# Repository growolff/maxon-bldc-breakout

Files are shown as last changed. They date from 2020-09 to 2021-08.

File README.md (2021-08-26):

# maxon_bldc_pcb

[][cc-by]

PCB para controlador de motor maxon BLDC 5w

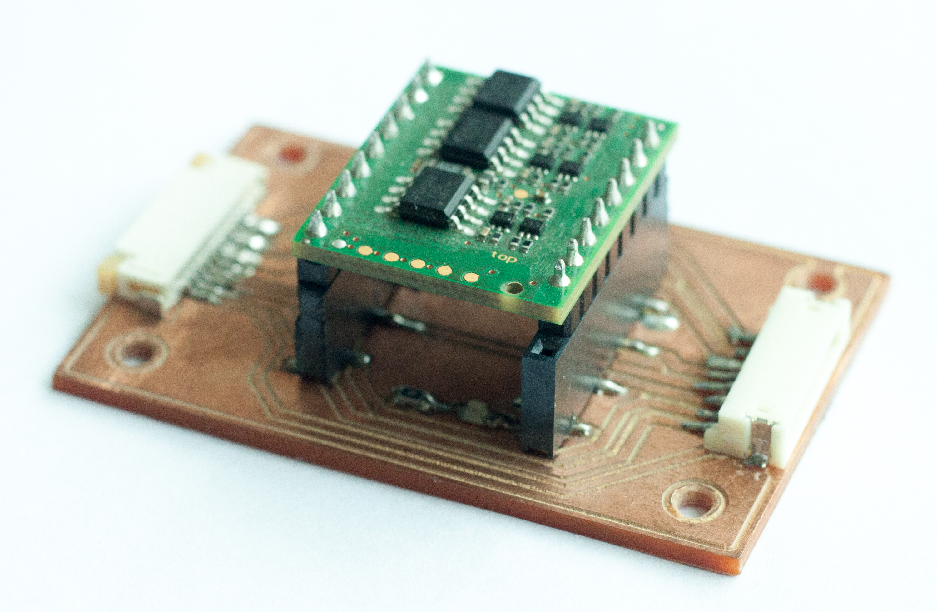
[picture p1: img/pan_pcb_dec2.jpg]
pcb hermosa con stencil


Este circuito fue diseñado como "breakout" para placa Maxon [1-Q-EC DEC module 24/2](https://www.maxongroup.us/maxon/view/news/MEDIENMITTEILUNG-DEC-Module-24-2) para controlar un motor BLDC [EC 20 flat](https://www.maxongroup.com/maxon/view/product/351005) también de maxon.

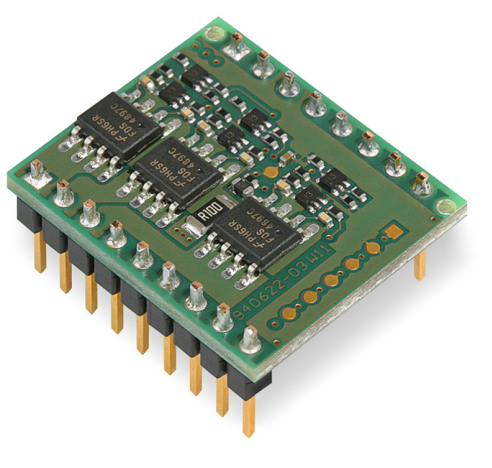
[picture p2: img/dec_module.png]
DEC module 24/2


La necesidad de hacer esta pcb tiene dos orígenes:

1. La disposición de los pines del DEC de maxon no esta pensada para una protoboard, o algo de tamaño estandar, debido a esa diferencia de 1.27mm entre las dos corridas de pines, lo que lo hace innecesariamente compliado para utilizar.

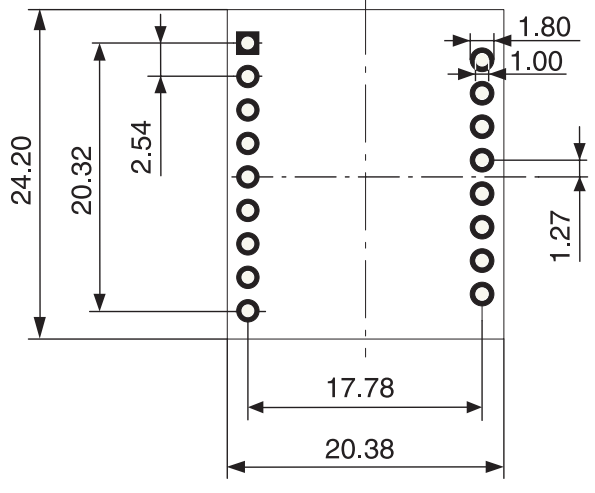
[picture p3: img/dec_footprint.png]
maldita disposición de los pines
  

2. Es necesario poder controlar el motor y comunicarse con el DEC utilizando un Arduino o cualquier otro microcontrolador por lo que hay que dejar los pines de alimentación del motor y GPIO disponibles.

## Diseño de la PCB

Por ahora, el circuito es el mínimo necesario para hacer funcionar el motor con el controlador. En las versiones posteriores se agregarán elementos de seguridad si es requerido.

El software utlizado para dieseñar la pcb fue [eagle](https://www.autodesk.com/products/eagle/overview) y los arhivos .sch y .brd los puedes encontrar en la carpeta [/cad](https://gitlab.com/growolff/maxon_bldc_pcb/-/tree/master/cad)

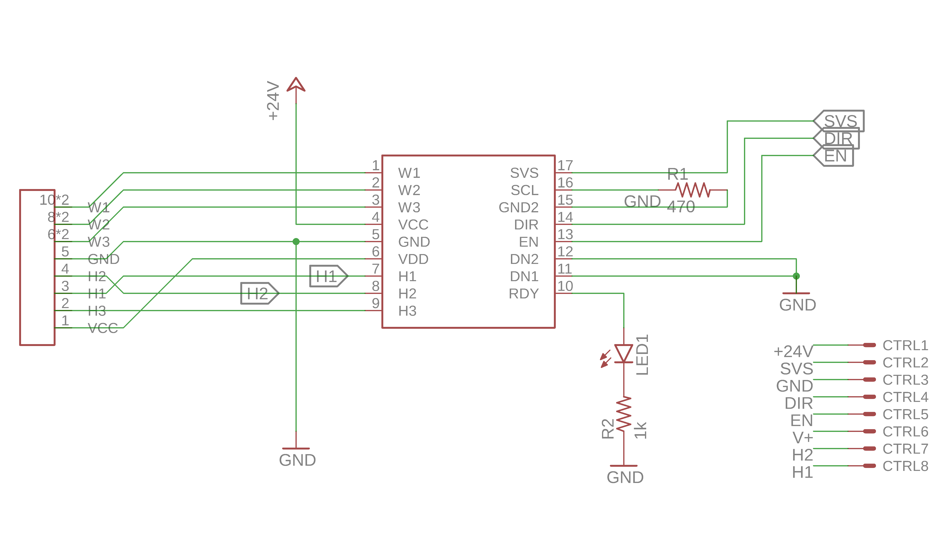
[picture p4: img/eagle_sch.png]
esquemático de eagle


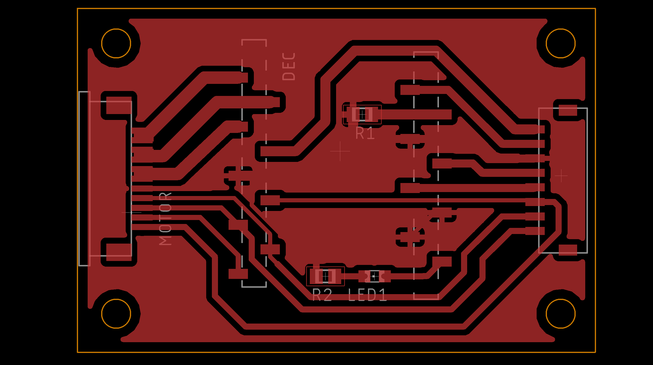
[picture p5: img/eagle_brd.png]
disposición de componentes en eagle


## Librería de egale

El módulo DEC lo puedes encontrar en mi librería de eagle [robot_hand.lbr](https://github.com/growolff/tesis-pcb/raw/master/my_lbr/robot-hand.lbr) en su versión actualizada con dos footprint, uno para montaje superficial (SMD) y otro para los típicos "through hole".

El footprint para montar el DEC superficialmente lo diseñé luego de encontrar estos maravillosos [headers hembra SMD](https://www.sparkfun.com/products/11543) en el mercado. Como el resto de los componentes de la pcb eran superficiales, ahorré mucho trabajo al  fabricar la placa en el [FabLab](http://fablab.uchile.cl) ya que solo necesité fresar una cara de la placa de cobre.

hermosos pin header smd
hermosos pin header smd

### Symbol
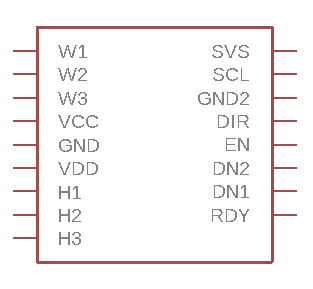
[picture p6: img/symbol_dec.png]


### Footprints
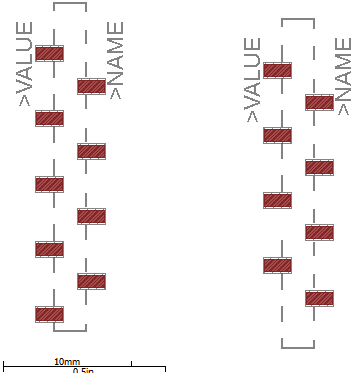
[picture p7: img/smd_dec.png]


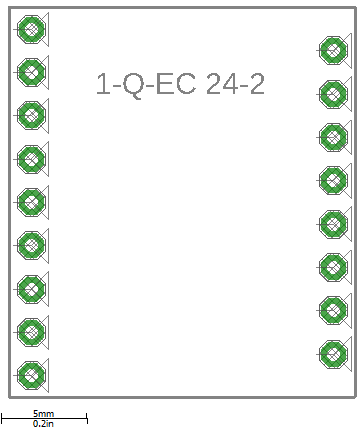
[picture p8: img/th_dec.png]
montaje through hole


## Licencia

Esta placa está publicada bajo la licencia [CC-BY-4.0][cc-by]

[][cc-by]

[cc-by]: https://creativecommons.org/licenses/by/4.0/
[cc-by-image]: https://i.creativecommons.org/l/by/4.0/88x31.png
[cc-by-shield]: https://img.shields.io/badge/License-CC%20BY%204.0-lightgrey.svg

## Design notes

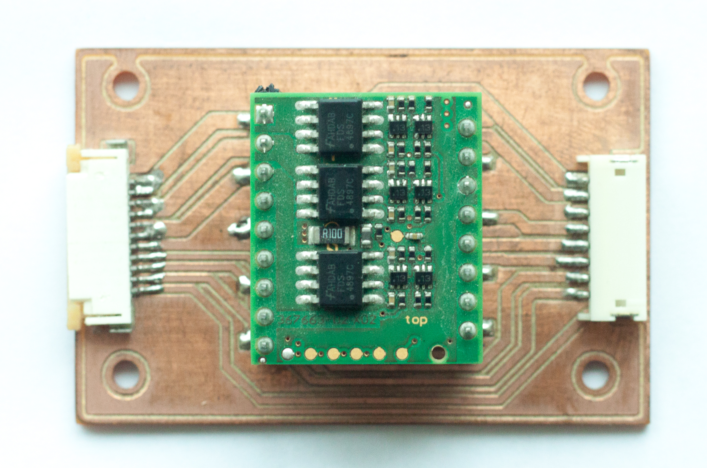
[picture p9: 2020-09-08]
img/top_pcb_dec.jpg

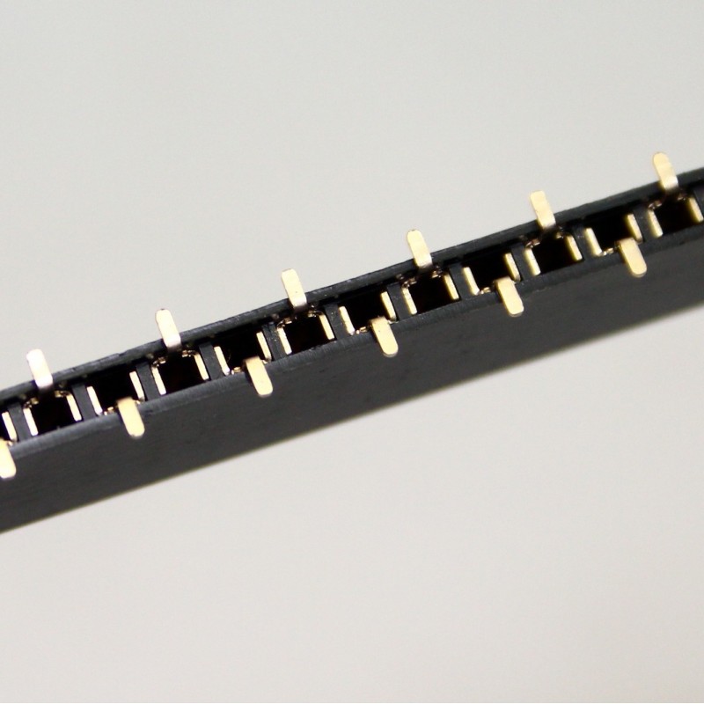
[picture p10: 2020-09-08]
img/smd_pinhead.jpg

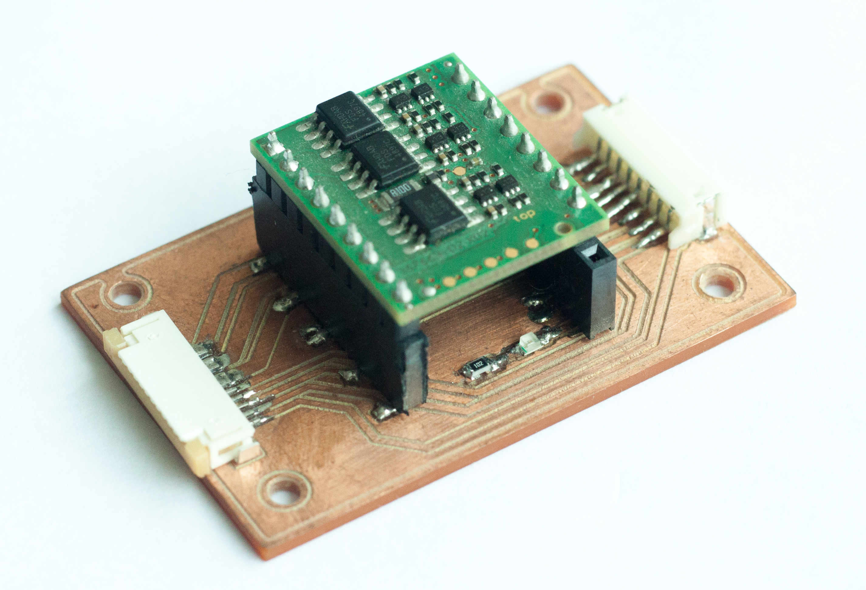
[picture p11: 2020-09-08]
img/pan_pcb_dec1.jpg

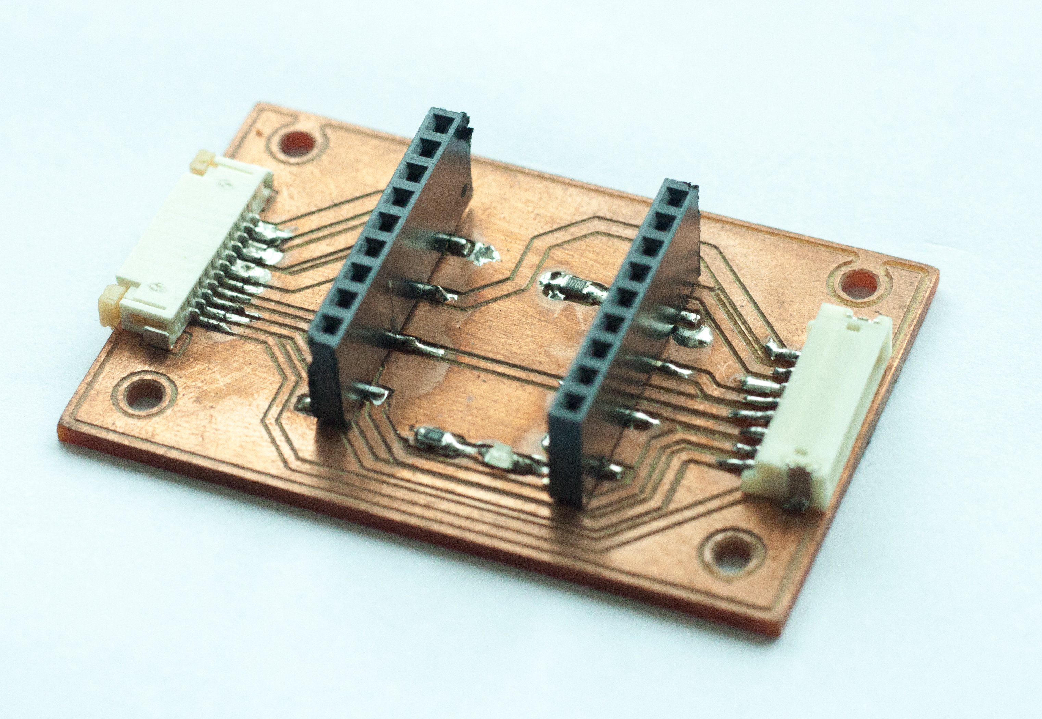
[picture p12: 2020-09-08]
img/pan_pcb.jpg

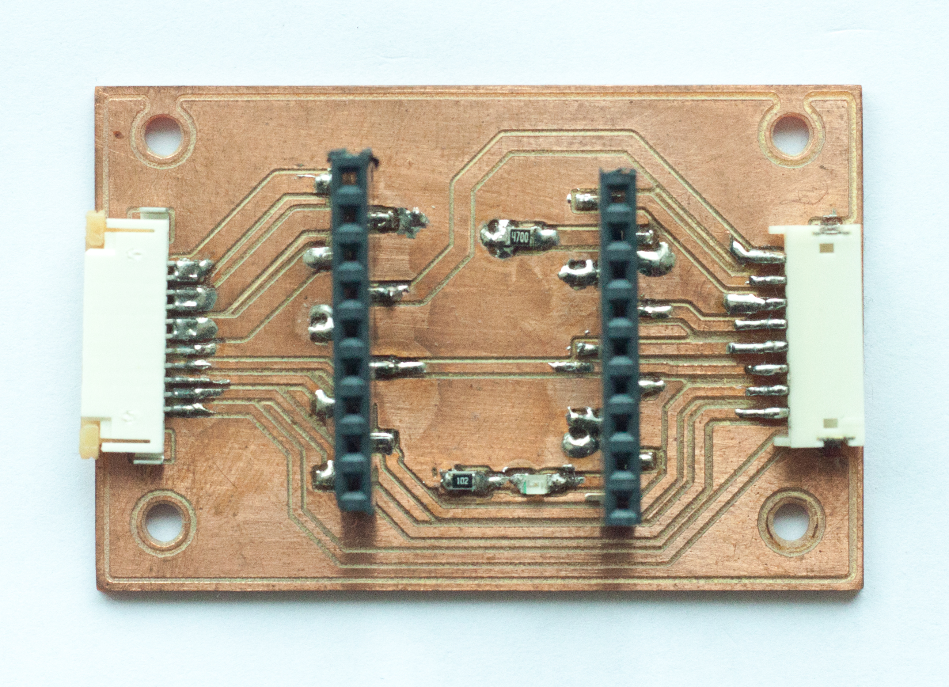
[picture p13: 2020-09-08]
img/top_pcb.jpg

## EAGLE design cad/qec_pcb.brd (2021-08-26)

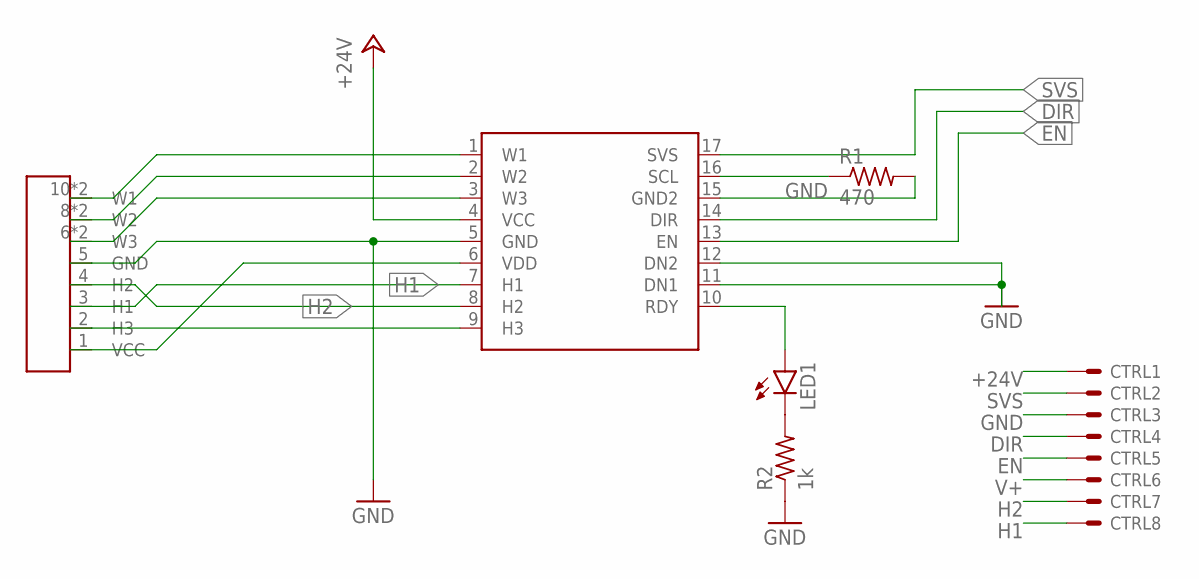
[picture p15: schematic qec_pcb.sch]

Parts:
CTRL: JST8; JST
DEC: 1-Q-EC1-Q-EC-SMD; 1-Q-EC-SMD
LED1: LEDCHIPLED_0805; CHIPLED_0805
MOTOR: 68611114122
R1: 470; M0805
R2: 1k; M0805

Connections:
+24V: CTRL.1, DEC.4 (VCC)
DIR: CTRL.4, DEC.14 (DIR)
EN: CTRL.5, DEC.13 (EN)
GND: CTRL.3, DEC.5 (GND), DEC.11 (DN1), DEC.12 (DN2), DEC.15 (GND2), MOTOR.5 (GND), R1.2, R2.1
H1: CTRL.8, DEC.7 (H1), MOTOR.3 (H1)
H2: CTRL.7, DEC.8 (H2), MOTOR.4 (H2)
H3: DEC.9 (H3), MOTOR.2 (H3)
unnamed: LED1.C, R2.2
unnamed: DEC.10 (RDY), LED1.A
unnamed: DEC.1 (W1), MOTOR.10 (W1), MOTOR.11 (W1)
unnamed: DEC.16 (SCL), R1.1
unnamed: DEC.2 (W2), MOTOR.8 (W2), MOTOR.9 (W2)
unnamed: DEC.3 (W3), MOTOR.6 (W3), MOTOR.7 (W3)
SVS: CTRL.2, DEC.17 (SVS)
V+: CTRL.6, DEC.6 (VDD), MOTOR.1 (VCC)

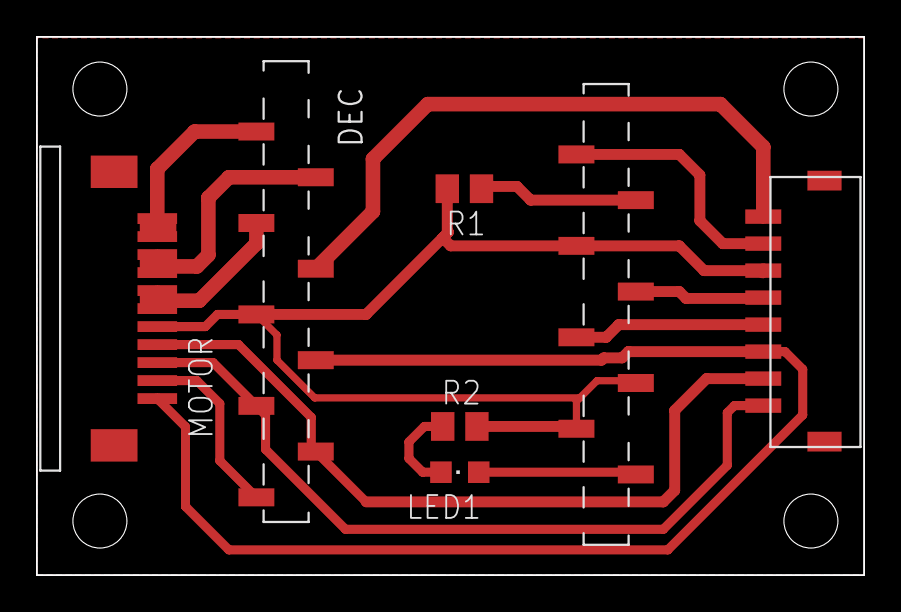
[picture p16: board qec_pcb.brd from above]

Board: 2 copper layers, 46.0 x 29.9 mm, 6 parts (0 on the bottom side), 15 nets.

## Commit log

2020-09-08 update readme, add imgs and cad files
    [qec_pcb.brd, qec_pcb.sch]
2020-09-09 Update README.md, se agrega link de la carpeta /cad
2021-08-26 update pcb for production
    [qec_pcb.brd, qec_pcb.sch]
